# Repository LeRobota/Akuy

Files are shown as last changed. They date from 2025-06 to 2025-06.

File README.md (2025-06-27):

# Akuy – Air Quality Visualizer

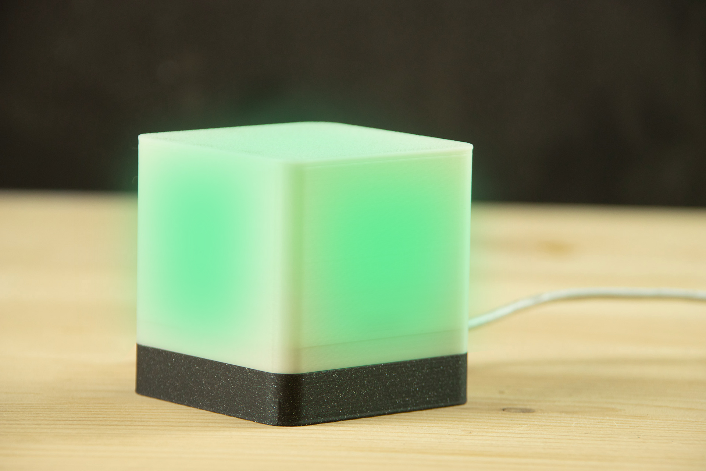
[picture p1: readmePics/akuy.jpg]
akuy

This project serves a dual purpose: introducing users to IoT (Internet of Things) and raising awareness of an invisible but crucial data point in our environment – **air quality**. The kit can be built at home for around 10 euros.
Akuy connects to the nearest air quality monitoring station and retrieves the **AQI (Air Quality Index)** – an international scale used to evaluate air quality and identify the presence of various pollutants. It then displays the AQI value using an RGB LED that changes color from **green to purple**, corresponding to the AQI reference scale (green = clean air, purple = heavily polluted).
Unlike a mobile app, Akuy is **constantly visible**, highlighting an otherwise imperceptible environmental factor. This allows users to monitor air quality throughout the day — provided the nearest station supplies reliable data.
If you're already familiar with **Arduino**, you can follow the tutorial below to build your own.

### ⚠️ A video showing the full assembly (in french) is available here : 
https://youtu.be/SbpglD8BQSg

---

## 🧰 Components
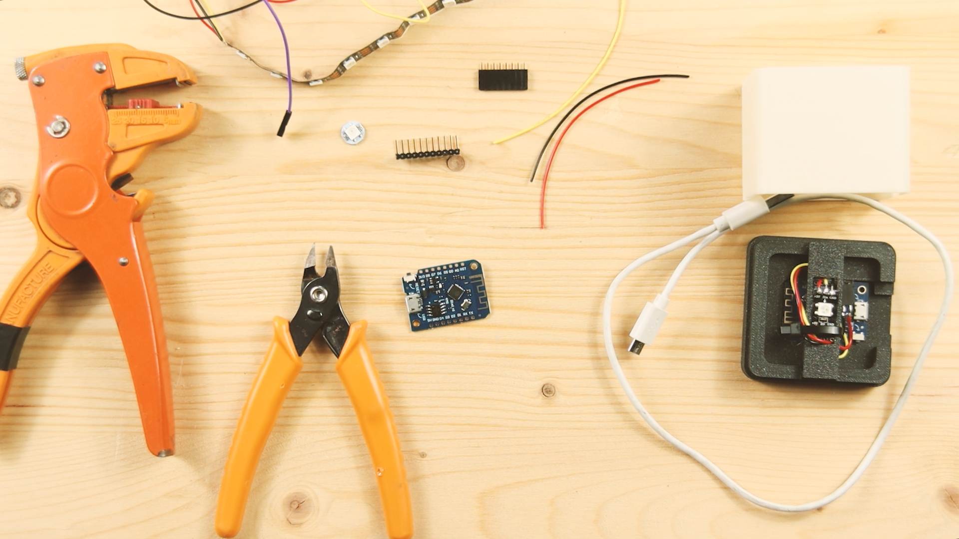
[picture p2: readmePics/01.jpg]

- [Lolin D1 Mini board](https://www.gotronic.fr/art-carte-wemos-d1-mini-v4-47521.htm)
- [Addressable RGB LED](https://www.gotronic.fr/art-mini-led-rgb-neopixel-ada4356-30782.htm)
- 3 jumper wires (preferably of different colors)
- [2.54mm female headers](https://www.gotronic.fr/art-connecteur-fh1x3-22729.htm)
- [2.54mm angled male headers](https://www.gotronic.fr/art-epuise-34687.htm)
- Micro USB or USB-C cable (depending on your Lolin model)
- 3D printer filament: *any color* for the base, *white/translucent* for the top

---

## 🛠️ Assembly Instructions
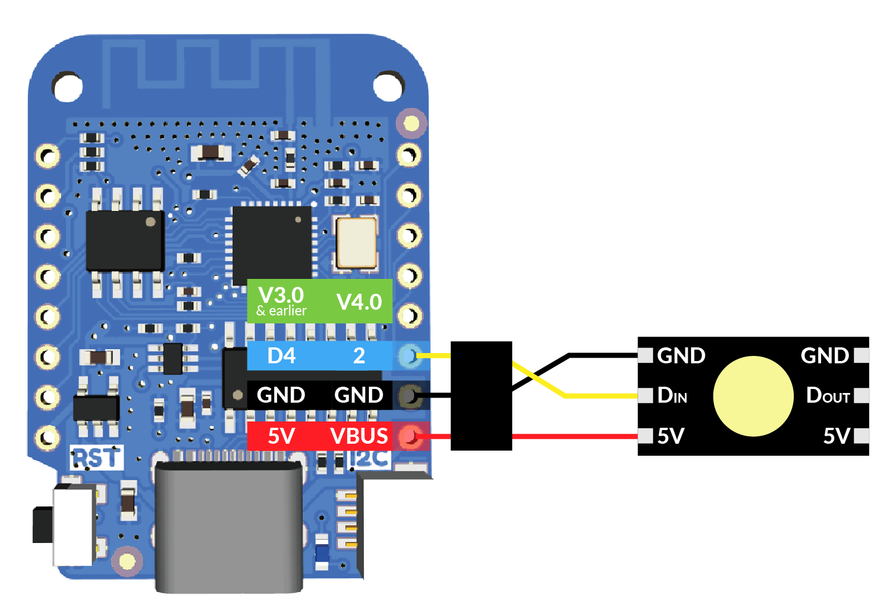
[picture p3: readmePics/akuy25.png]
schema

### Step 0
Print the 3D parts. Use **white, transparent or translucent filament** for the top part of the object to diffuse the LED light.

### Step 1
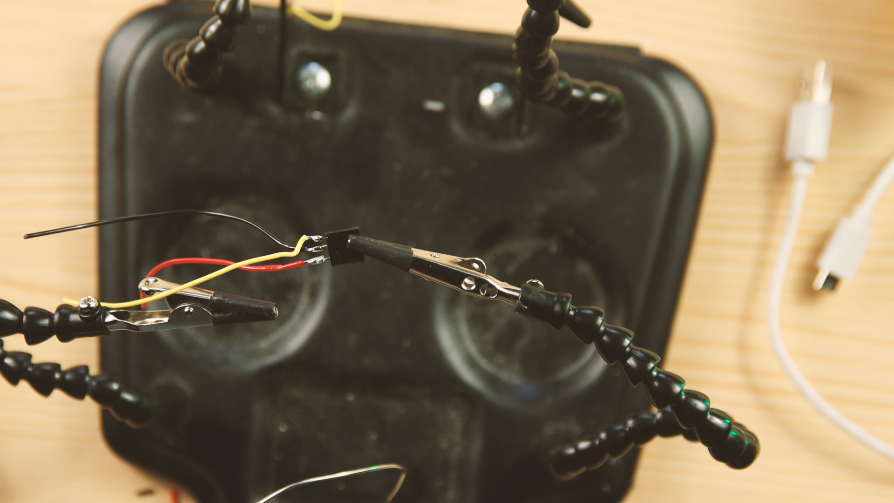
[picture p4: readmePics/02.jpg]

Strip and solder your 3 jumper wires to the **female header connector**. Make sure **GND is in the center**.

### Step 2
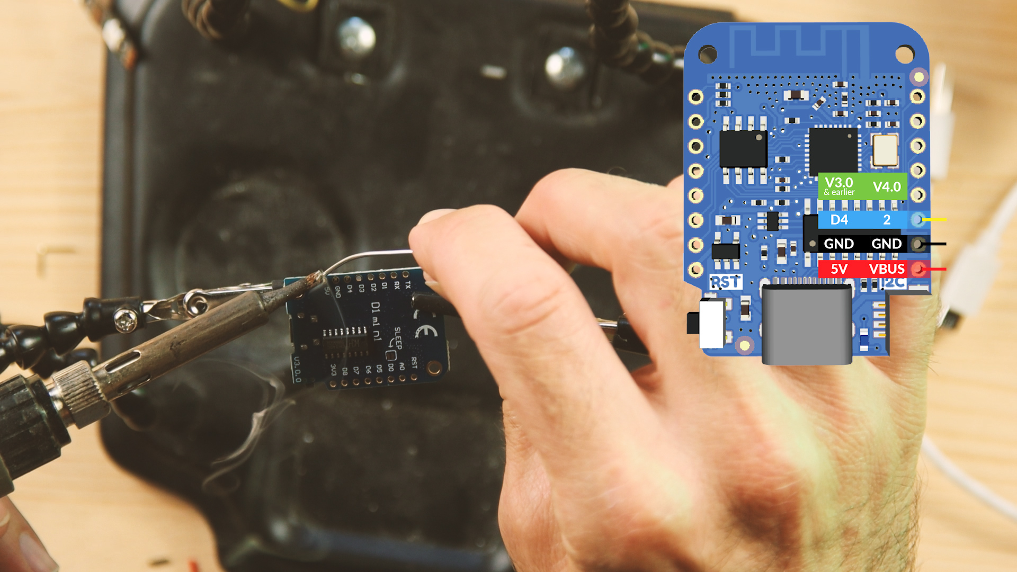
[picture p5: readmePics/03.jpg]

Solder the **angled male headers** to the **top side** of the Lolin board (USB port side).

- For versions V1, V2, V3: use pins `5V`, `GND`, `D4`.
- For version V4: use pins `VBUS`, `GND`, `2`.

### Step 3
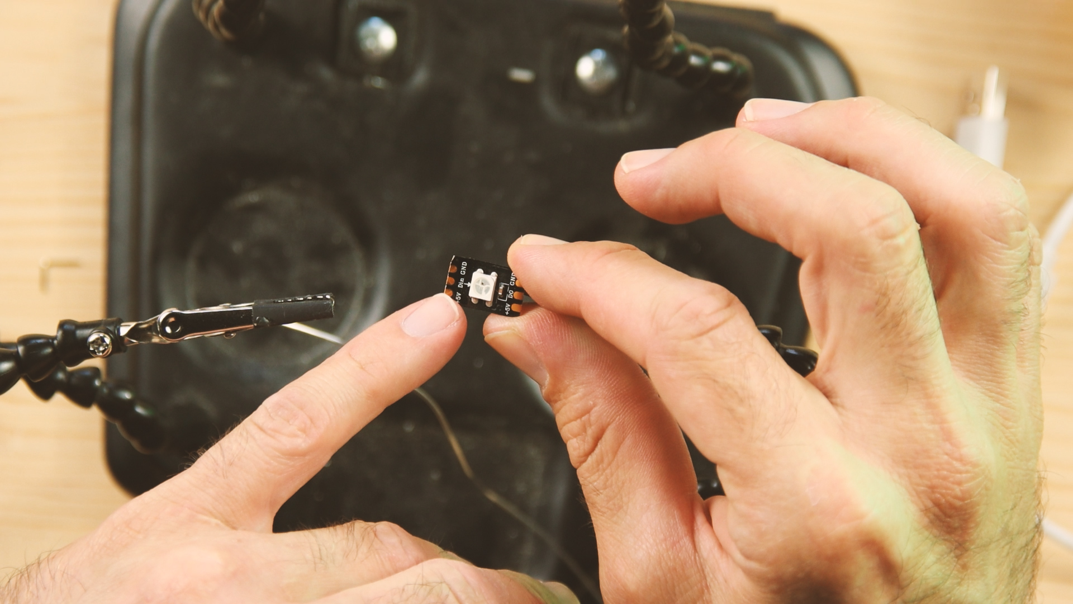
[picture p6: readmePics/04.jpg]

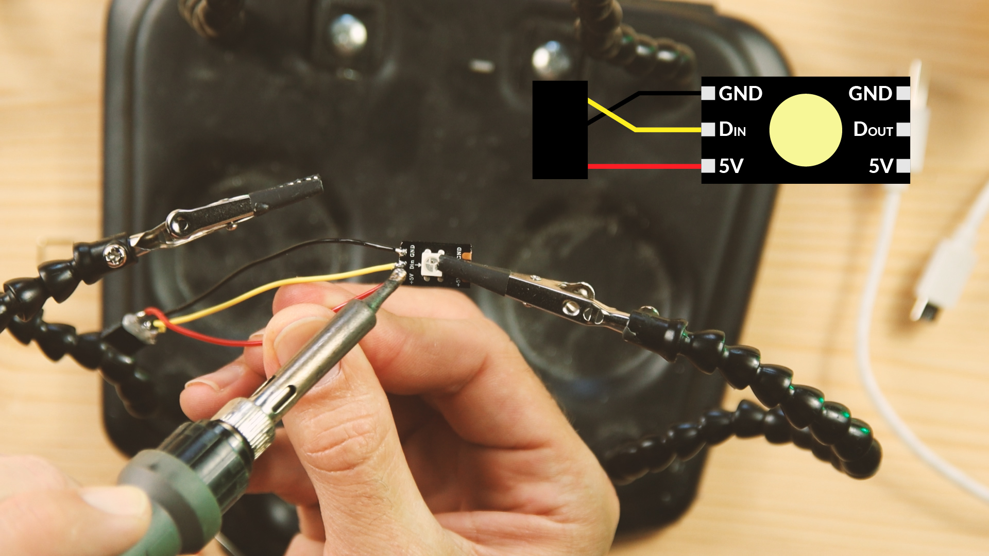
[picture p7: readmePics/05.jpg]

Solder the pins on your LED. Be sure to use the **“Din”** side (not “Dout”).

### Step 4
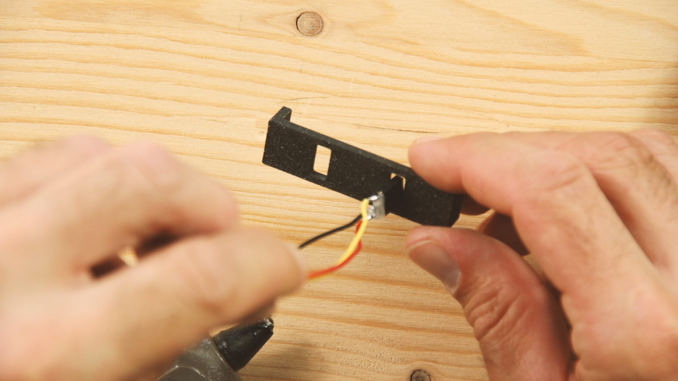
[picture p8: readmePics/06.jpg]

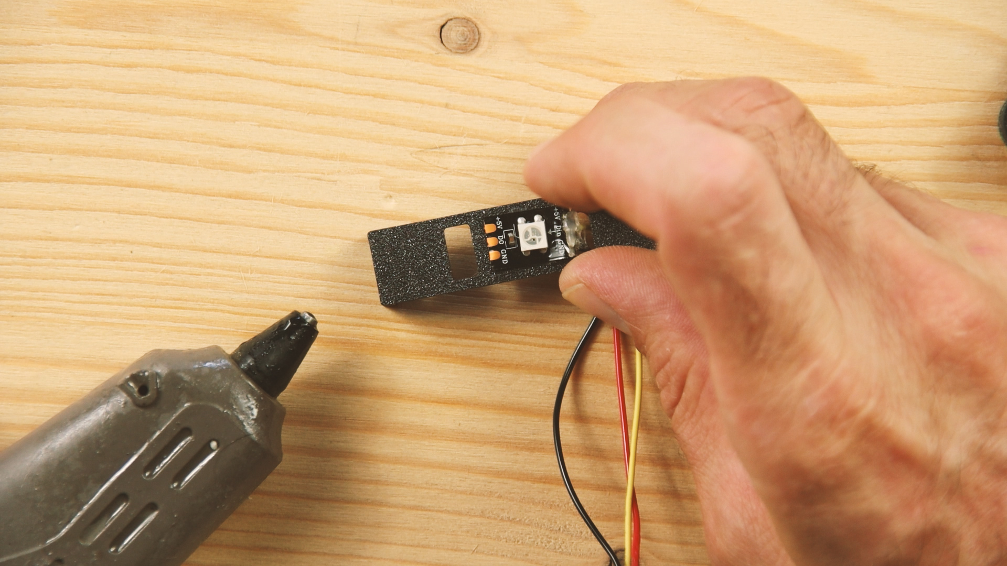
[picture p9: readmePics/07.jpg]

Using a hot glue gun (or the LED’s adhesive, if present), glue the LED to the 3D-printed part **after** passing the **female header connector through the rectangular hole**.

### Step 5
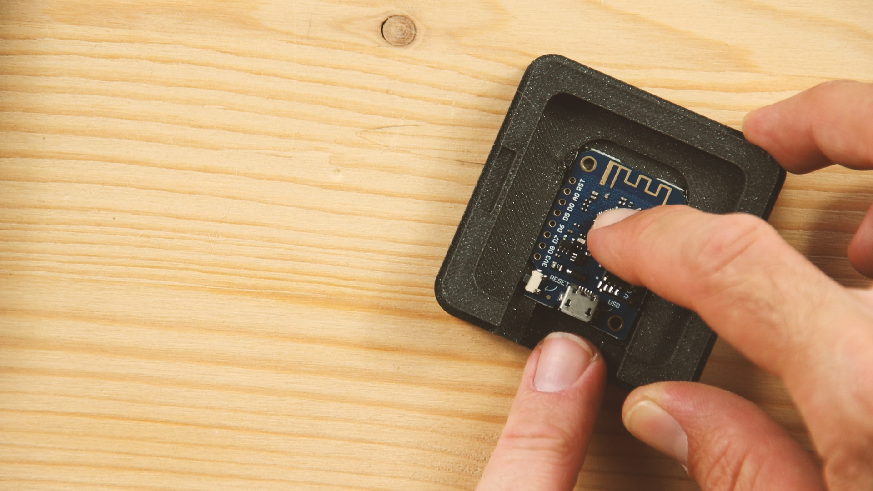
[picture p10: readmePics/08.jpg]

Secure the Lolin board into its 3D-printed housing using a small amount of hot glue.  
⚠️ Don’t use too much glue if you plan to reuse the board later.

### Step 6
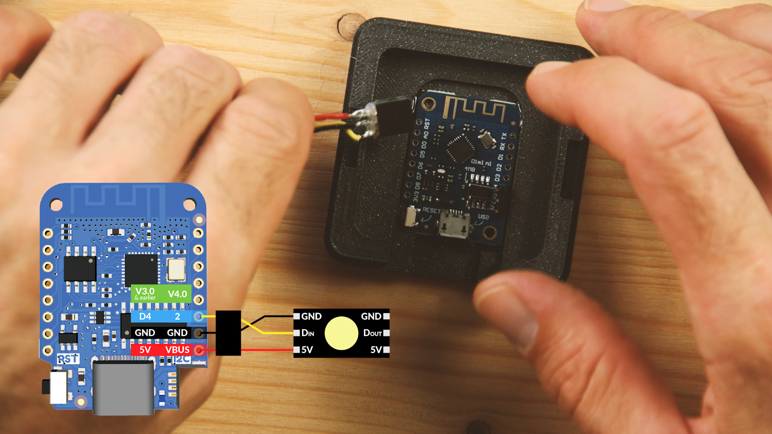
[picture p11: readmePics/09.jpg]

Connect the **male and female headers**, following the correct wire order as per the diagram.

### Step 7
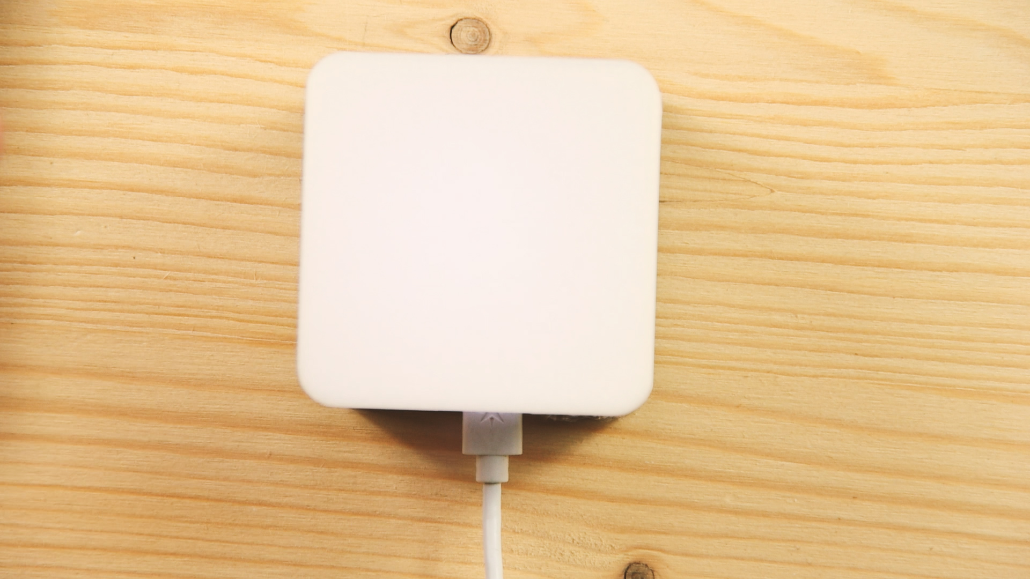
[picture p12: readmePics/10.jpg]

Connect your board via USB. If the LED lights up, the connections are good.  
You're ready to move on to **programming**.

---

## 💻 Programming Akuy

### Step 8
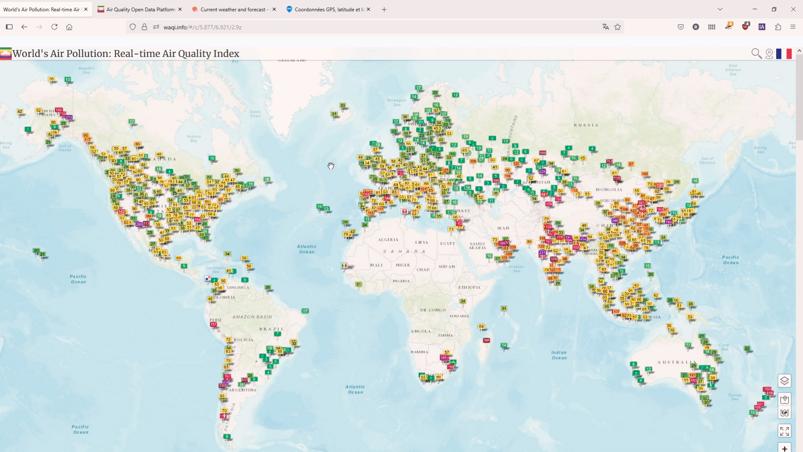
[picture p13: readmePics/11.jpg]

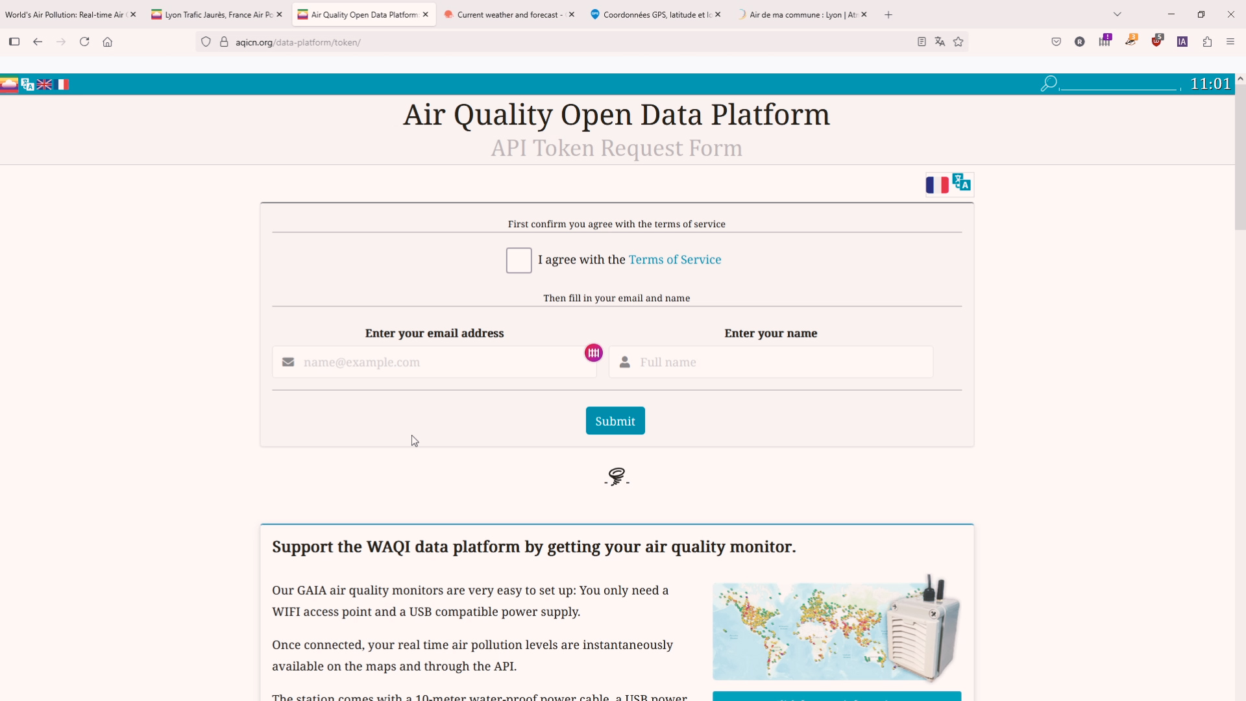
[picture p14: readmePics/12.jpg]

This tutorial uses data from [https://waqi.info](https://waqi.info).  
Other providers such as OpenWeatherMap also offer similar services.

To access the air quality API, you’ll need a free token. Request it here:  
👉 [https://aqicn.org/data-platform/token/](https://aqicn.org/data-platform/token/)

### Step 9
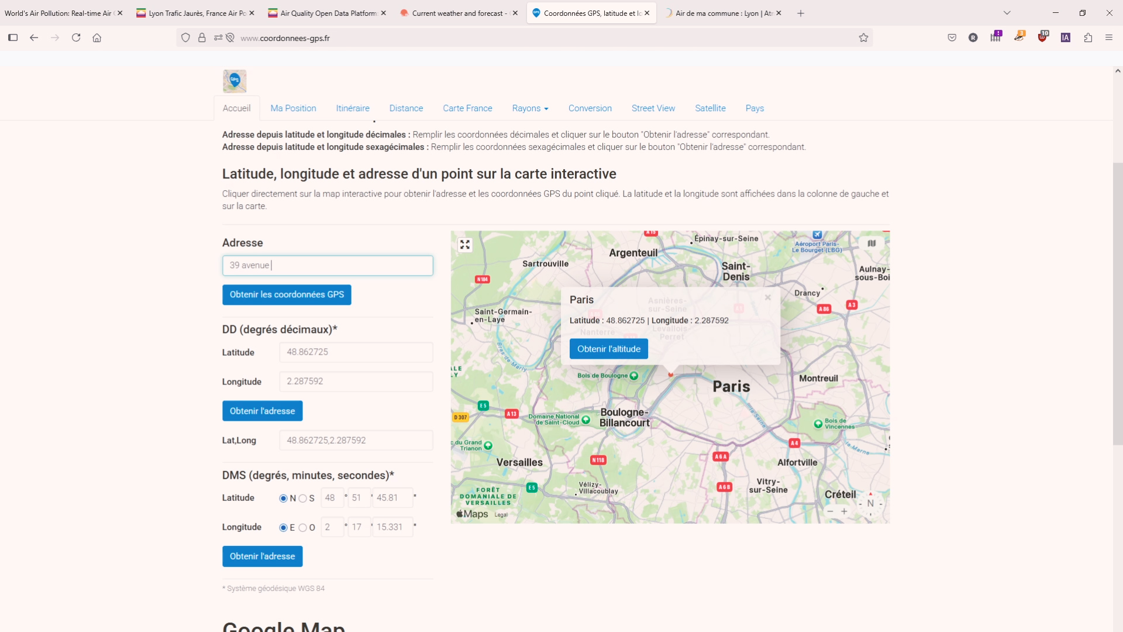
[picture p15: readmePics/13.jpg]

You’ll also need the **GPS coordinates** of the location where you want to get AQI data.  
You can find them here: 👉 [https://www.gps-coordinates.net/](https://www.gps-coordinates.net/)

### Step 10
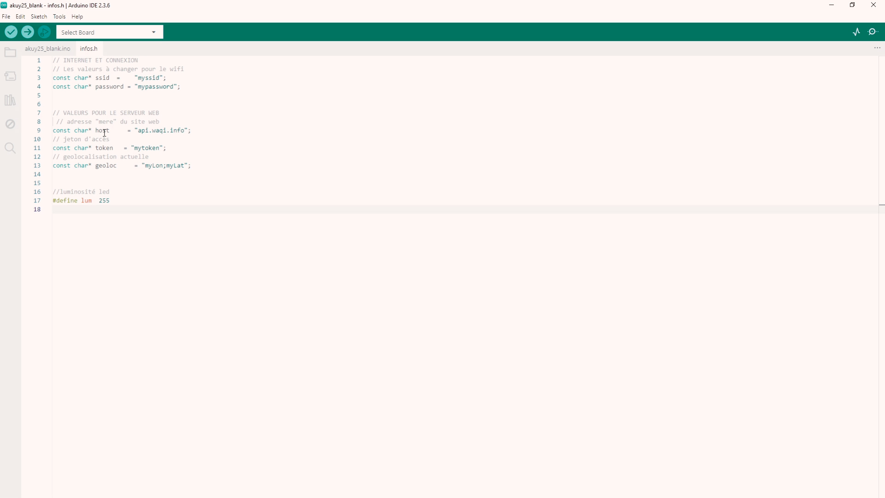
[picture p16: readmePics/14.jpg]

Open the `akuy25_blank` file in the **Arduino IDE**.  
(Download the IDE for free here: [https://www.arduino.cc/en/software/](https://www.arduino.cc/en/software/))

In the `infos.h` tab, replace the placeholders with:

- Your **WiFi SSID**
- Your **WiFi password**
- Your **AQI token** (from Step 8)
- **Latitude and Longitude** of your desired location

Optional: adjust the LED brightness (max: `255`).

⚠️ If you're sharing your code publicly, remember to **remove your WiFi credentials** beforehand!

### Step 11
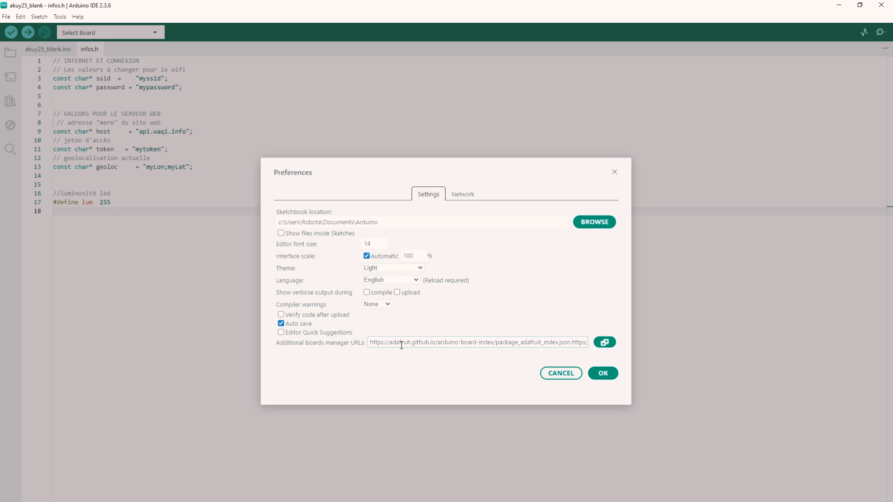
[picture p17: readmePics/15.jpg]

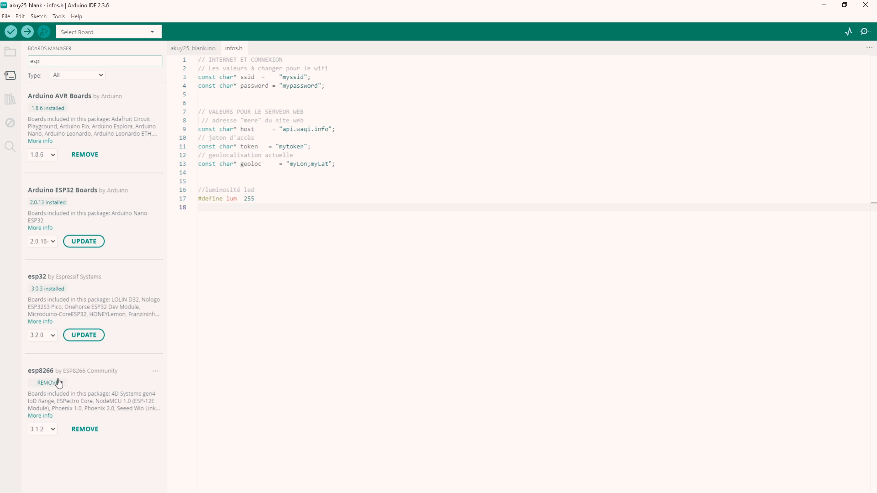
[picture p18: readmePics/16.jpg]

If you’ve never programmed an **ESP8266** with Arduino:

1. Go to: `File > Preferences > Additional Boards Manager URLs`
2. Add this URL:  
   `http://arduino.esp8266.com/stable/package_esp8266com_index.json`
3. Click the **Boards Manager icon** (top-left) and search for “esp”.
4. Install the **ESP8266 board package**.

### Step 12
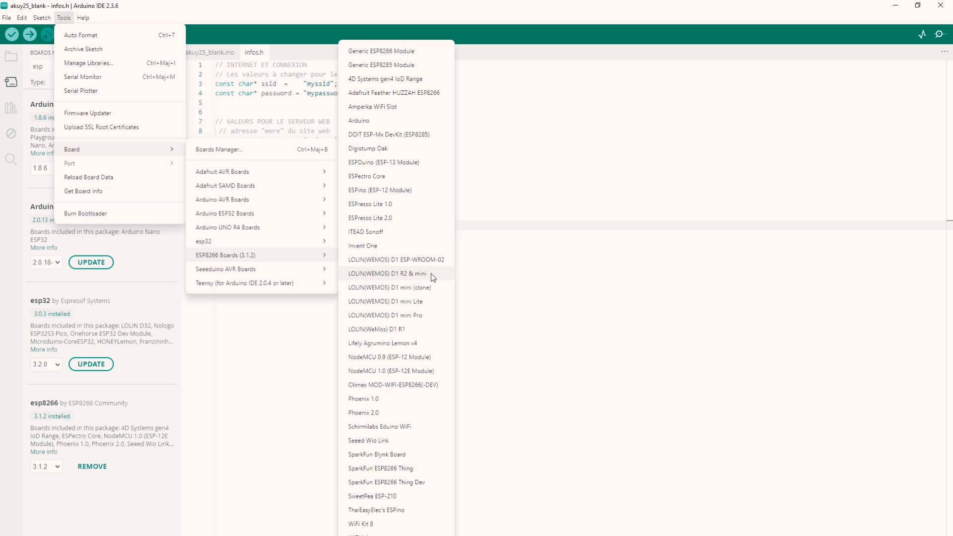
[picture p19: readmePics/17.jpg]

In `Tools > Board`, select:

- `LOLIN(WEMOS) D1 R2 & Mini`

In `Tools > Port`, select the port your board is connected to.

Upload the program.

---

## ✅ Done!

- The LED will remain **blue** while attempting to connect to WiFi.
- If it **stays blue**, the connection failed.

⚠️ Note: **ESP8266 only supports 2.4GHz WiFi**, not 5GHz networks.

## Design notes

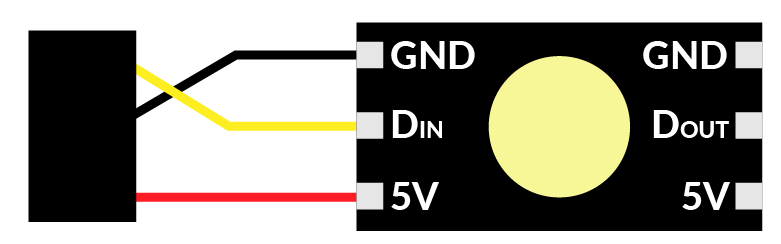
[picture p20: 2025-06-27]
readmePics/akuy25 schemas-03.png

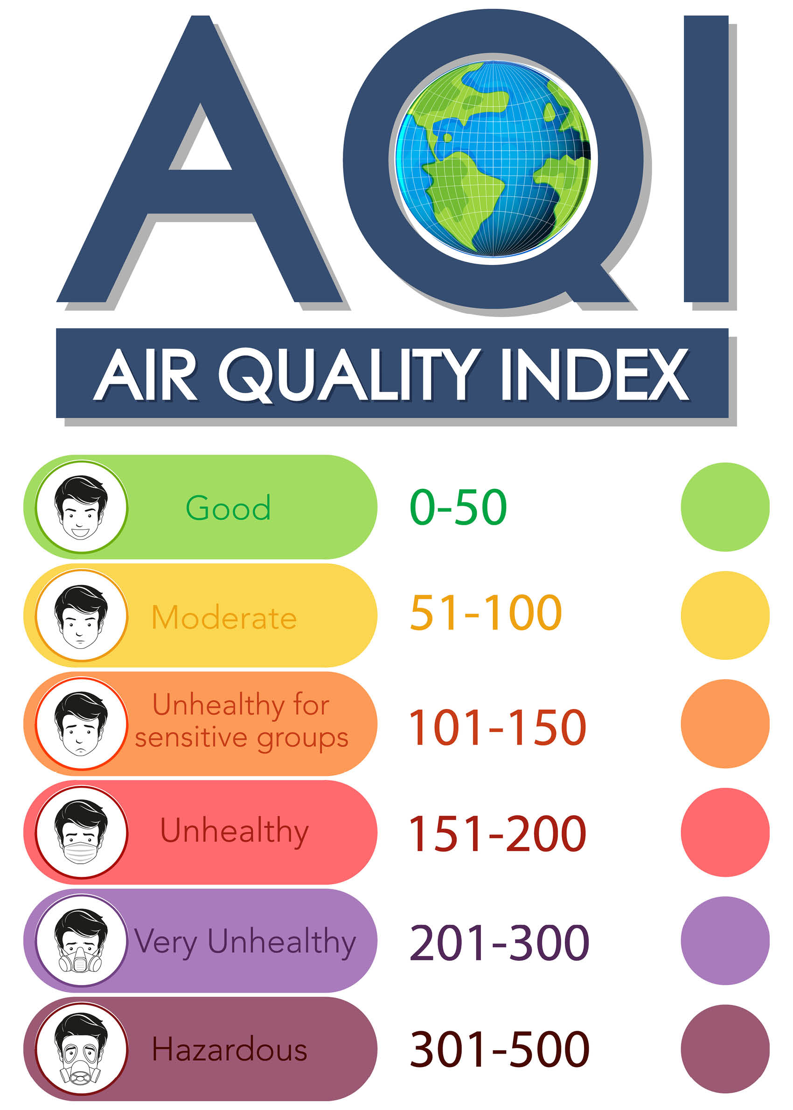
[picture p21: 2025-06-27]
readmePics/AQI-Scale_low-res-2364787702.jpg

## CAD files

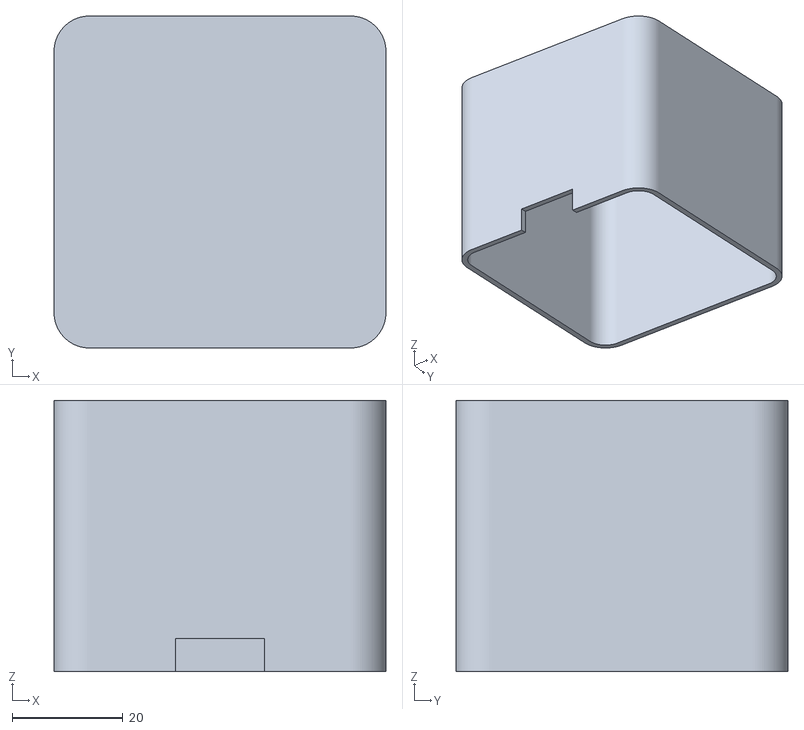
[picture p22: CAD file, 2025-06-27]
STL/Akuy25_top.stl
60.0 x 60.0 x 49.0

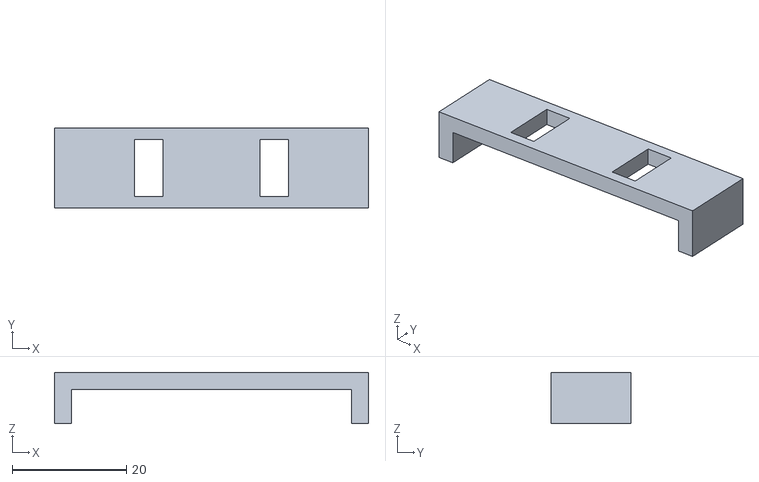
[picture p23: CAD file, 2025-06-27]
STL/Akuy25_led_support.stl
55.0 x 14.0 x 9.00

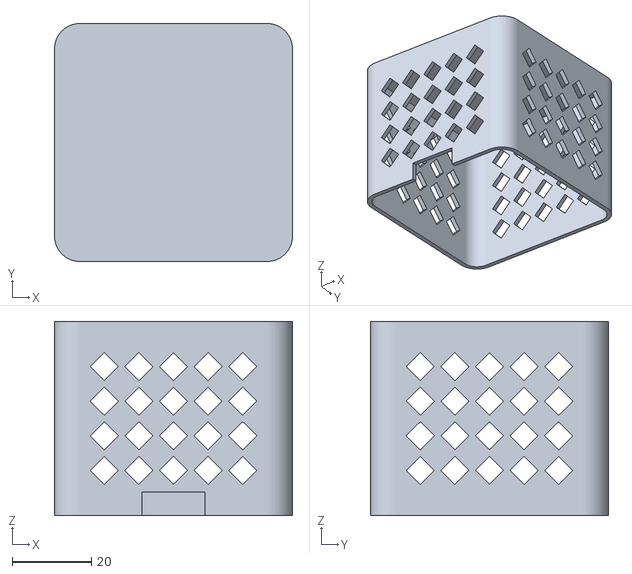
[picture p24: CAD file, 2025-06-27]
STL/Akuy25_top_alt.stl
60.0 x 60.0 x 49.0

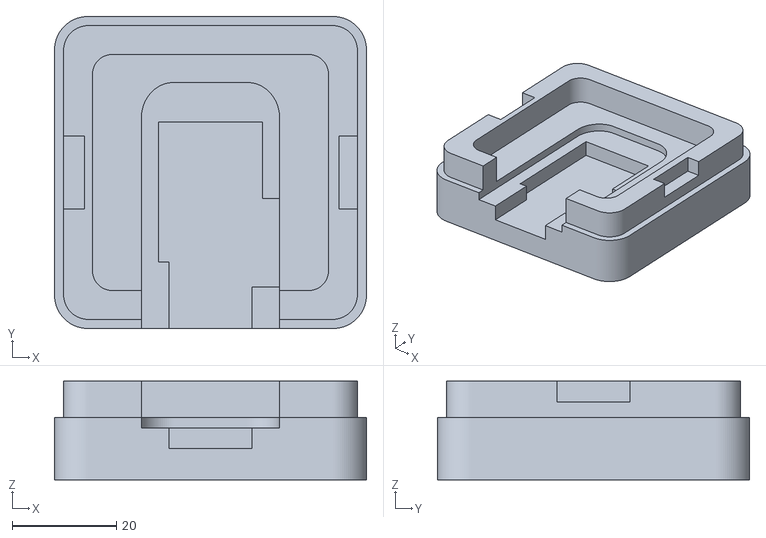
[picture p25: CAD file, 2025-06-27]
STL/Akuy25_base.stl
60.0 x 60.0 x 19.0

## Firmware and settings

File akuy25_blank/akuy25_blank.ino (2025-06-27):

#include "infos.h" 
#include <ESP8266WiFi.h>
#include <FastLED.h>

#define DATA_PIN D4
#define NUM_LEDS 1

CRGB leds[NUM_LEDS];

String keyword = "\"aqi\":";
float score_aqi;

unsigned long previousRequestTime = 0;
const unsigned long interval = 1800000;

void setup() {
  Serial.begin(115200);
  FastLED.addLeds<WS2811, DATA_PIN, GRB>(leds, NUM_LEDS);
  FastLED.setBrightness(lum);

  Serial.print("Connexion WiFi");
  WiFi.begin(ssid, password);
 
  while (WiFi.status() != WL_CONNECTED) {
    delay(500);
    leds[0] = CRGB::Blue;
    FastLED.show();
    Serial.print(".");
  }

  Serial.println("\nWiFi connecté");
  Serial.println(WiFi.localIP());


  AQIrequest();
  previousRequestTime = millis();
}

void loop() {
  unsigned long currentTime = millis();

  if (currentTime - previousRequestTime >= interval) {
    AQIrequest();
    previousRequestTime = currentTime;
  }

}

void AQIrequest() {
  WiFiClient client;
  const int httpPort = 80;
  if (!client.connect(host, httpPort)) {
    Serial.println("Connexion échouée");
    return;
  }

  String url = "/feed/geo:" + String(geoloc) + "/?token=" + token;
  client.print(String("GET ") + url + " HTTP/1.1\r\nHost: " + host + "\r\nConnection: close\r\n\r\n");

  delay(1000); 
  bool inBody = false;

  while (client.available()) {
    String line = client.readStringUntil('\r');

    if (line.length() == 1) inBody = true;
    if (inBody) {
      int pos = line.indexOf(keyword);
      if (pos > 0) {
        score_aqi = atof(&line[pos + keyword.length()]);
        break;
      }
    }
  }

  Serial.print("Score AQI : ");
  Serial.println(score_aqi);

  setColorBasedOnAQI(score_aqi);
}

void setColorBasedOnAQI(float aqi) {
  if (aqi < 50) leds[0] = CRGB::Green;          
  else if (aqi < 100) leds[0] = CRGB::Yellow;
  else if (aqi < 150) leds[0] = CRGB::Orange;    
  else if (aqi < 200) leds[0] = CRGB::Red;    
  else if (aqi < 300) leds[0] = CRGB::Violet; 
  else leds[0] = CRGB::Brown;

  FastLED.show();
}

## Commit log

2021-11-03 Akuy 2021 FR
    Commentaires FR.
    Ajout d'un fichier infos.h
    Ajout d'options de connexion
2021-11-03 guide de montage
    guide de montage
2025-06-27 Rename akuy25 schemas_Plan de travail 1.png to akuy25.png
